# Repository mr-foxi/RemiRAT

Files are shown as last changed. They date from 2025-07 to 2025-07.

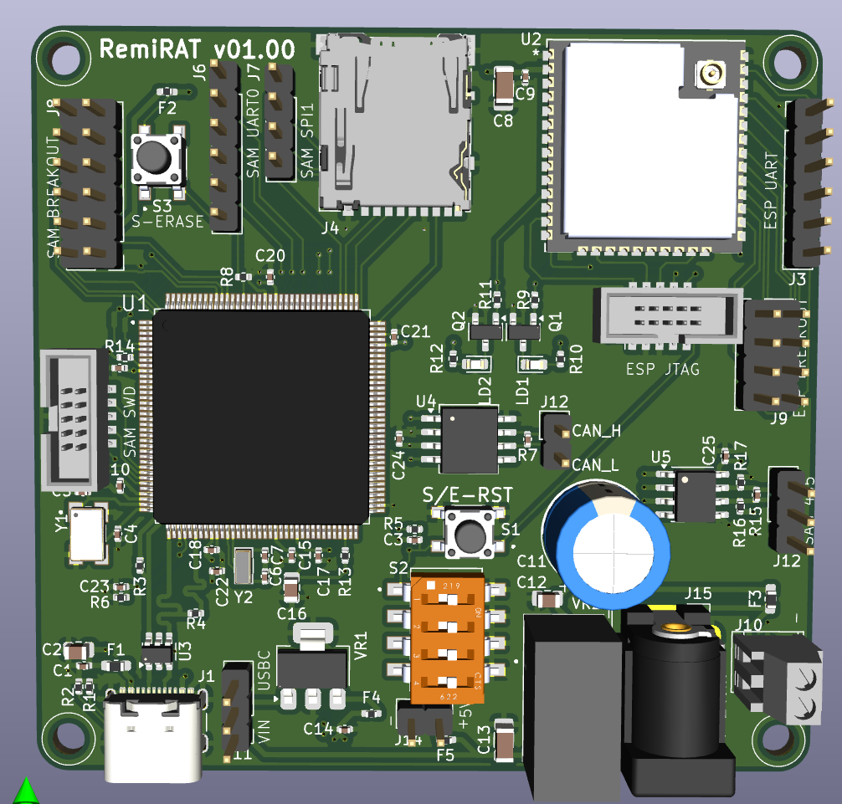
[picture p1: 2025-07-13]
PCB_TOP.png

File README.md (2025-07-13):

# RemiRAT: Versatile Open-Source Wireless Control & Automation Platform
The RemiRAT is a custom PCB that integrates the power of an Arduino Due (SAM3X8EA-AU) with the wireless capabilities of an ESP32-WROOM-32UE-N16 onto a single, compact board. This unified platform condenses complex, multi-board development setups into a streamlined solution, enhancing integration and reliability for advanced control and automation projects.

## Key Features:

Dual Microcontrollers: Combines the SAM3X8EA-AU for high-performance real-time tasks and extensive I/O (including DMA for efficient data handling and RTC support for accurate time-keeping) with the ESP32 for seamless Wi-Fi/Bluetooth connectivity and cloud integration, supporting an external antenna for optimal range.

Robust Industrial Communication: Features dedicated CANBUS (SN65HVD230DR) and MODBUS-RS485 (MAX485CSA+T) transceivers, ensuring reliable data exchange in industrial, automotive, and other demanding environments, complete with proper termination and failsafe biasing for signal integrity.

Diverse Peripherals: Offers comprehensive Digital and Analog I/O, supporting common protocols like UART, SPI, I2C, PWM, and includes a MicroSD card slot for flexible data logging and storage.

Flexible Power Management: Accepts a broad 6.5-32V input via a robust barrel jack or screw terminal, or via USB-C for convenience. It features efficient multi-stage regulation providing stable 5V and 3.3V outputs, backed by integrated fuse protection and USB ESD protection for enhanced durability.

Developer Friendly: Provides multiple options for easy firmware development, including UART, JTAG, and SWD flashing capabilities for both MCUs, along with an ESP32 boot mode DIP switch and clearly labeled breakout headers.

RemiRAT stands as a powerful, robust, and highly integrated solution for tackling complex wireless control and IoT applications with confidence.

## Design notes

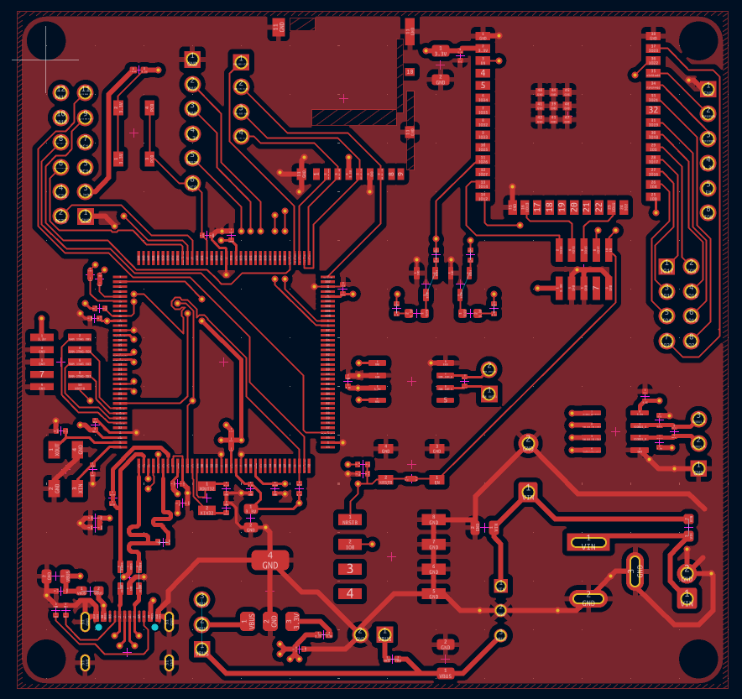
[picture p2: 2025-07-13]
Cu_TOP.png

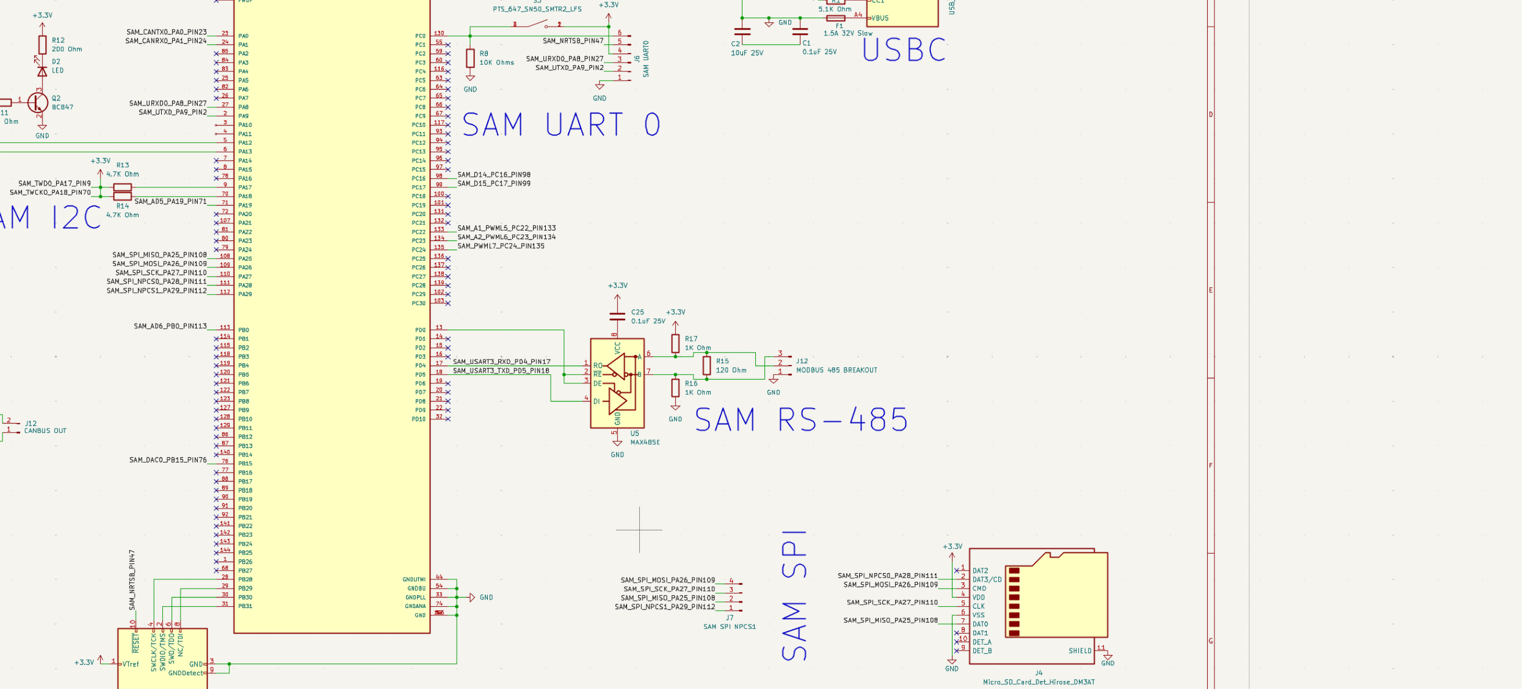
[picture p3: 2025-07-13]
Schem_04.png

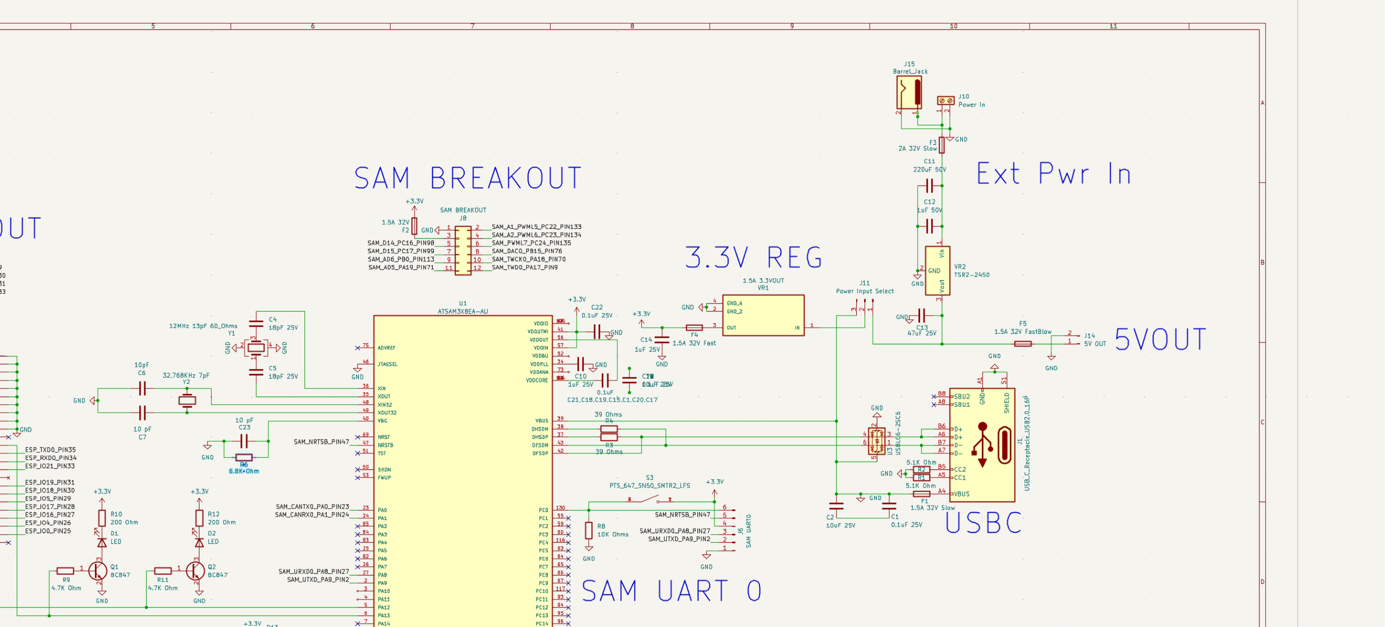
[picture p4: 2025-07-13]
Schem_03.png

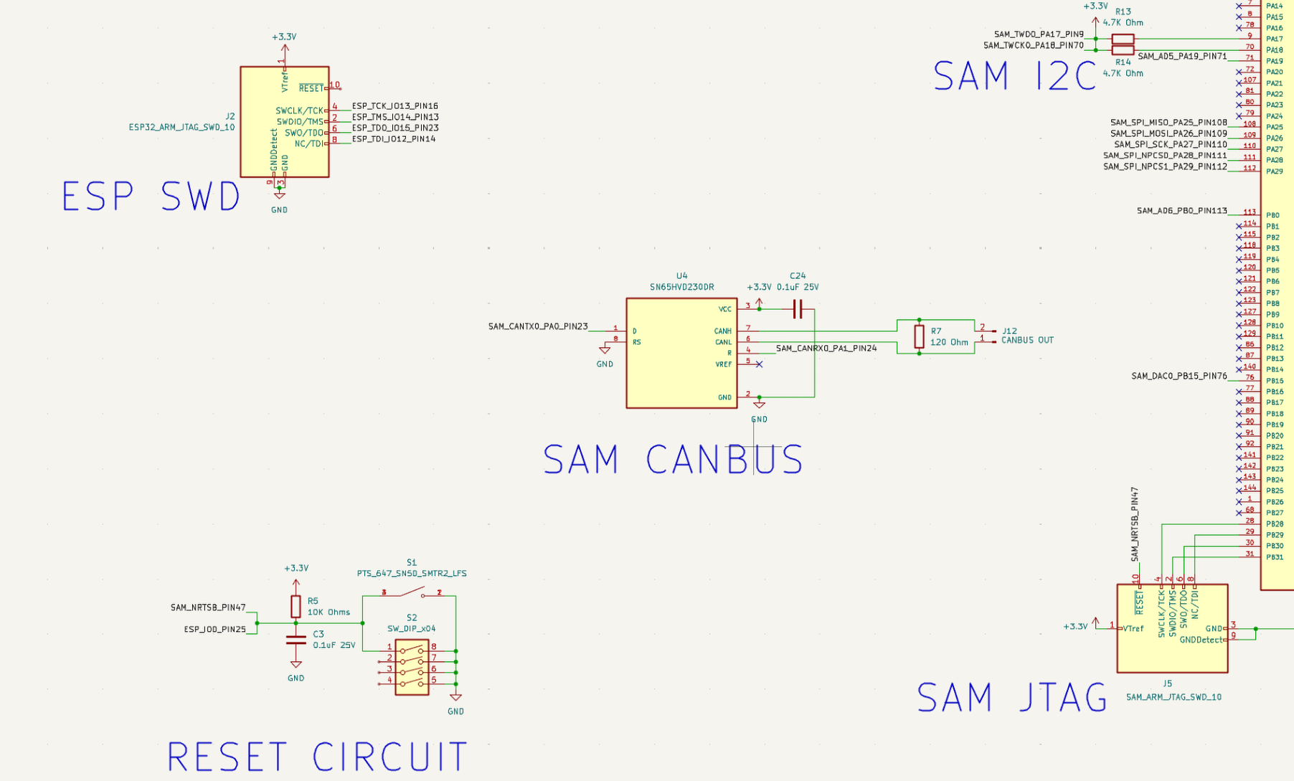
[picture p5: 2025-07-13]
Schem_01.png

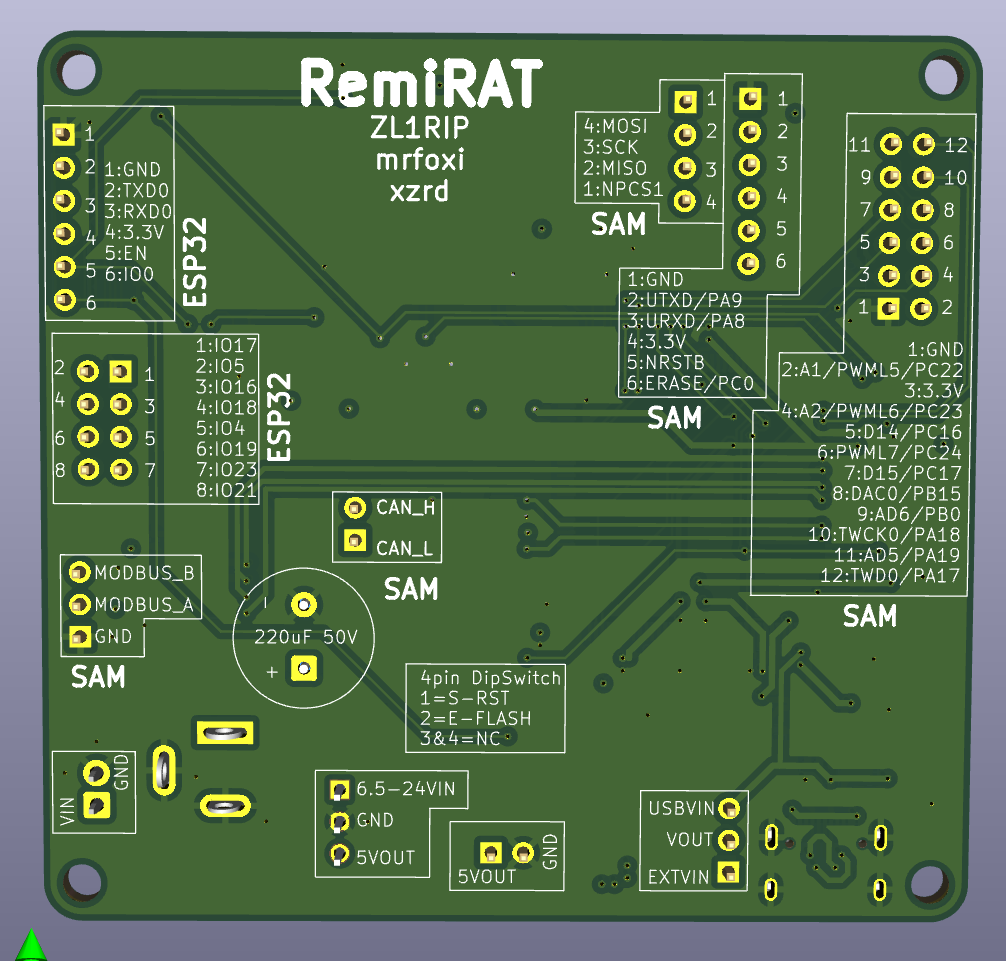
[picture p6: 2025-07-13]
PCB_BOTTOM.png

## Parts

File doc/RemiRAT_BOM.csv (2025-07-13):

Id | Designator | Footprint | Quantity | Designation | Manufacturer | Manufacturer Part Number | Notes
1 | J9 | PinHeader_2x04_P2.54mm_Vertical | 1 | Header 2x04 Pin 2.54mm Vertical | Samtec Inc. | TSW-104-07-F-D | Generic Header
2 | R11,R9,R13 | R_0402_1005Metric | 2 | Resistor 4.7k Ohm 1% 0402 | Yageo | RC0402FR-074K7L | Pull-up/down, specific for SAM or ESP
3 | J3,J6 | PinHeader_1x06_P2.54mm_Vertical | 2 | Header 1x06 Pin 2.54mm Vertical | Würth Elektronik | 61300611121 | e.g., Serial Flashing Headers
4 | C23,C7,C6 | C_0402_1005Metric | 3 | Capacitor 10pF 25V 0402 | KYOCERA AVX | KGM05ACG1E100KH | Crystal Load Capacitors
5 | S3,S1 | SW_PTS_647_SN50_SMTR2_LFS | 2 | Tactile Switch SPST-NO SMD | C&K Components | PTS647SN50SMTR2LFS | Reset/Erase Buttons
6 | Q2,Q1 | SOT-23-3 | 2 | N-Channel MOSFET SOT-23 | Anbon | BC847B | RX/TX LED Transistor
7 | R4,R3 | R_0402_1005Metric | 2 | Resistor 39 Ohm 1% 0402 | Stackpole Electronics Inc | RMCF0402JT39R0 | USB D+/D- Termination
8 | R5,R8 | R_0402_1005Metric | 2 | Resistor 10k Ohm 1% 0402 | Yageo | RC0402FR-0710KL | Pull-up/down for control lines
9 | C8 | C_1206_3216Metric | 1 | Capacitor 22uF 25V X5R 1206 | Samsung Electro-Mechanics | CL31A226KAHNNNE | Bulk Decoupling/Output Cap for ESP32
10 | U1 | QFP50P2200X2200X145-144N | 1 | ATSAM3X8AE-AU MCU | Microchip | ATSAM3X8EA-AU | Main Microcontroller
12 | LD1,LD2 | LED_0603_1608Metric | 2 | LED Green 0603 | Kingbright | APT1608CGCK | RX/TX ESP/SAM LEDs
13 | J4 | microSD_HC_Hirose_DM3AT-SF-PEJM5 | 1 | MicroSD Card Connector | Hirose | DM3AT-SF-PEJM5 | MicroSD Slot
14 | VR1 | SOT-223 | 1 | LDO Regulator 3.3V 1.5A | STMicroelectronics | TL1963A-33DCYR | 3.3V Power Supply
15 | R7,R15 | R_0402_1005Metric | 2 | Resistor 120 Ohm 1% 0402 | Vishay Dale | CRCW0402120RFKEDC | CABUS Noise Resistor
16 | Y1 | XTAL_405C35B12M00000 | 1 | Crystal 12MHz 13pF 4-SMD | CTS-Frequency Controls | 405C35B12M00000 | Main SAM MCU Crystal
17 | R1,R2 | R_0402_1005Metric | 2 | Resistor 5.1k Ohm 1% 0402 | Yageo | RC0402FR-075K1L | Could be USB pull-ups or other
18 | J7 | PinHeader_1x04_P2.54mm_Vertical | 1 | Header 1x04 Pin 2.54mm Vertical | Würth Elektronik | 61300411121 | e.g., Test Points, I2C
19 | R10,R12 | R_0402_1005Metric | 2 | Resistor 200 Ohm 1% 0402 | Delta Electronics/Cyntec | PFR05S-201-FNH | LED Current Limiting
20 | C2,C16 | C_0805_2012Metric | 1 | Capacitor 10uF 25V X5R 0805 | Samsung Electro-Mechanics | CL21A106KAYNNNE | Input/Output Decoupling
21 | J1 | USB_C_Receptacle_GCT_USB4105-xx-A_16P_TopMnt_Horizontal | 1 | USB-C Receptacle Horizontal | GCT | USB4105-GF-A | USB Connector
22 | J2,J5 | PinHeader_2x05_P1.27mm_Vertical_SMD | 2 | Header 2x05 Pin 1.27mm Vert SMD | CNC Tech | 3220-10-0300-00 | e.g., SWD/JTAG Headers
23 | S2 | SW_219-4MST | 1 | DIP Switch 4-Pos SPST | CTS Electrocomponents | 219-4MST | e.g., ESP32 Boot Mode Select
24 | J8 | PinHeader_2x06_P2.54mm_Vertical | 1 | Header 2x06 Pin 2.54mm Vertical | TE Connectivity AMP Connectors | 87227-6 | e.g., Generic Expansion Header
25 | U2 | ESP32-32UE_EXP | 1 | ESP32-WROOM-32UE Module | Espressif Systems | ESP32-WROOM-32UE-N16 | Wi-Fi/BT Module
26 | C4,C5 | C_0402_1005Metric | 2 | Capacitor 18pF 25V C0G 0402 | KYOCERA AVX | KGM05ACG1E180FH | Crystal Load Capacitor
28 | C25,C24,C22,C21,C20,C19,C18,C17,C15,C9,C3,C1 | C_0402_1005Metric | 12 | Capacitor 0.1uF 25V X7R 0402 | Samsung Electro-Mechanics | CL05B104KA5NNNC | Local Decoupling
29 | F2,F5 | Fuse_0402_1005Metric_Pad0.77x0.64mm_HandSolder | 2 | Fuse 1.5A 32V 0402 FastBlow | Littelfuse | 043501.5KRHF | Overcurrent Protection
30 | Y2 | Crystal_SMD_3215-2Pin_3.2x1.5mm | 1 | Crystal 32.768kHz 7pF 3.2x1.5mm | Seiko Instruments | SC32S-7PF20PPM | RTC Crystal for SAM
31 | U3 | SOT-23-6 | 1 | Voltage Supervisor SOT-23-6 | STMicroelectronics | USBLC6-2 | Example, specify part type (e.g. voltage supervisor, op-amp, logic IC)
32 | F3 | Fuse_0603_1608Metric_Pad1.05x0.95mm_HandSolder | 1 | 2A 32V SlowBlow | Bourns Inc. | SF-0603SP200-2 | Wire Input Power Fuse
33 | VR2 | CONV_TSR_2-2450 | 1 | Wire Power Input Voltage Regulator | Traco Power | TSR 2-2450 | 6.5-36VIN 2A 5VOUT
34 | C12 | C_0805_2012Metric | 1 | 1uF 50V | Samsung Electro-Mechanics | CL21B105KBFNNNE
35 | J10 | TerminalBlock_TE_282834-2_1x02_P2.54mm_Horizontal | 1 | 2pin Screw Terminal | TE Connectivity AMP Connectors | 1546215-2
36 | J11,J13 | PinHeader_1x03_P2.54mm_Vertical | 1 | PinHeader_1x03_P2.54mm_Vertical | Würth Elektronik | 61300311121
37 | C13 | C_1206_3216Metric | 1 | 47uF 25V | TDK Corporation | C3216X5R1E476M160AC | Bulk Decoupling/Output Cap for external power in
38 | C10,C14 | C_0402_1005Metric | 2 | Capacitor 1uF 25V X5R 0402 | Samsung Electro-Mechanics | CL05A105KA5NQNC | Local Decoupling
39 | R6 | R_0402_1005Metric | 1 | Resistor 6.8K Ohm 1% 0402 | TE Connectivity Passive Product | CRGCQ0402F6K8 | Voltage Bias Pin Pulldown Resistor
40 | U4 | SOIC-8_5.3x6.2mm_P1.27mm | 1 | 1/1 IC Transceiver Half CANbus 8-SOIC | Texas Instruments | SN65HVD230DR | CANBUS Communication Chip
41 | J12,J14 | PinHeader_1x02_P2.54mm_Vertical | 2 | Header 1x02 Pin 2.54mm Vertical | Würth Elektronik | 61300211121 | CANBUS Breakout
42 | U5 | SOIC-8_5.3x6.2mm_P1.27mm | 1 | 1/1 Transceiver Half RS422, RS485 8-SOIC | Analog Devices Inc./Maxim Integrated | MAX485CSA+T | RS-485 Communication Chip
43 | R16,R17 | R_0402_1005Metric | 2 | Resistor 1K Ohm 1% 0402 | YAGEO | RC0402JR-071KL | Modbus Noise Reduction Resistors
44 | F1 | Fuse_0402_1005Metric_Pad0.77x0.64mm_HandSolder | 1 | Fuse 1.5A 36V 0402 SlowBlow | Bourns Inc. | SF-0603SP150M-2 | USBC Power fuse
45 | J15 | CONN PWR JACK 2.1X5.5MM SOLDER | 1 | Power Barrel Connector Jack 2.10mm ID (0.083"), 5.50mm OD (0.217") Through Hole, Right Angle | Würth Elektronik | 694106301002 | BarrelJack DC Input (2.1mm pin)

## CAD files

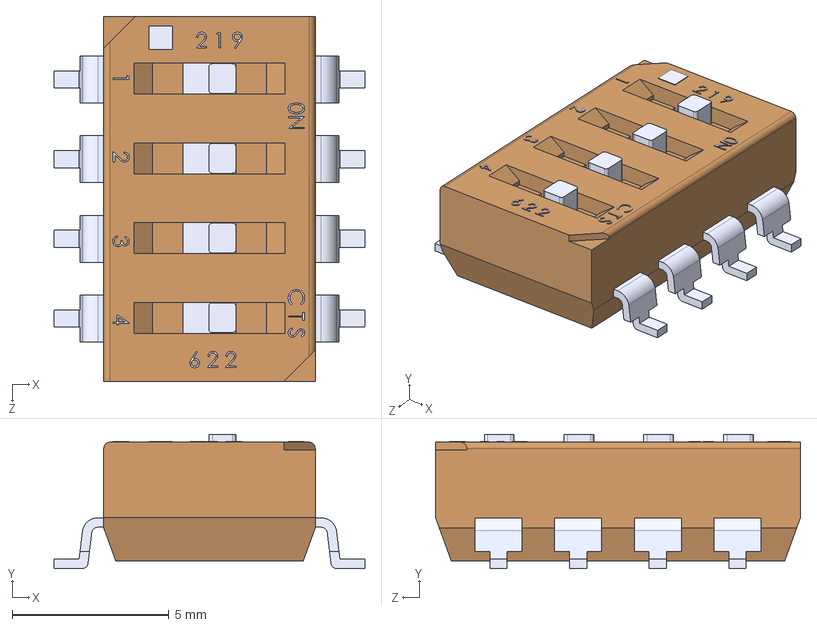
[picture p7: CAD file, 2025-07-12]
coreLib/219_4MST/219-4M.step
9.91 x 4.28 x 11.6 mm

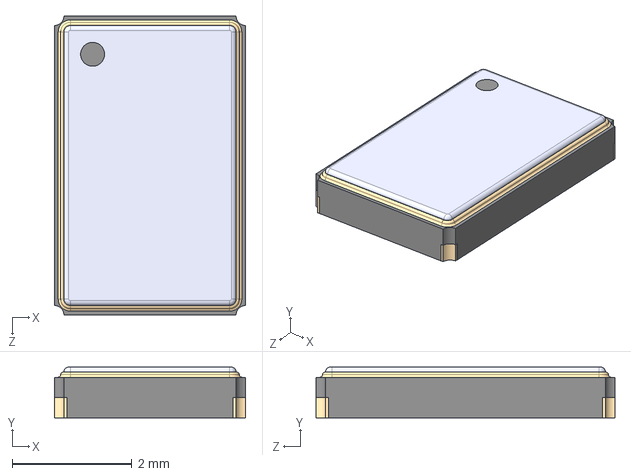
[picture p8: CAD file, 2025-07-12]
coreLib/405C35B12M00000/405C35B12M00000.STEP
3.20 x 0.85 x 5.00 mm

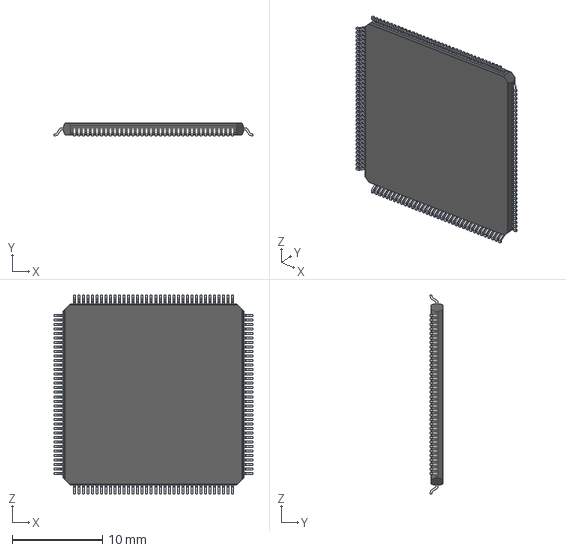
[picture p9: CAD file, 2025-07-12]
coreLib/ATSAM3X8EA_AU/atsam3x8ea-au.stp
22.0 x 1.40 x 22.0 mm

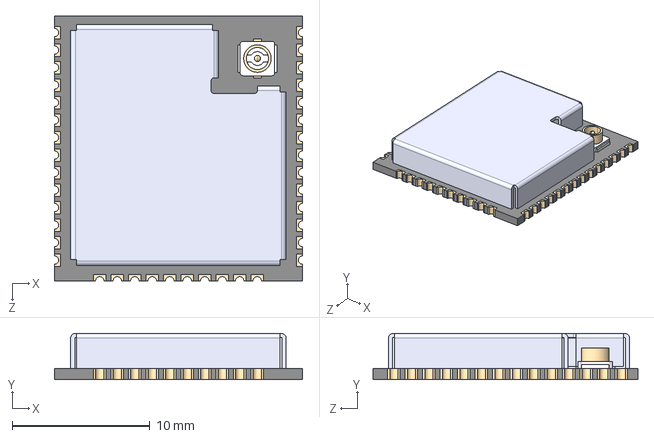
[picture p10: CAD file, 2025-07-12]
coreLib/ESP32-WROOM-32UE-N16/ESP32-WROOM-32UE-N16.STEP
18.0 x 3.35 x 19.2 mm

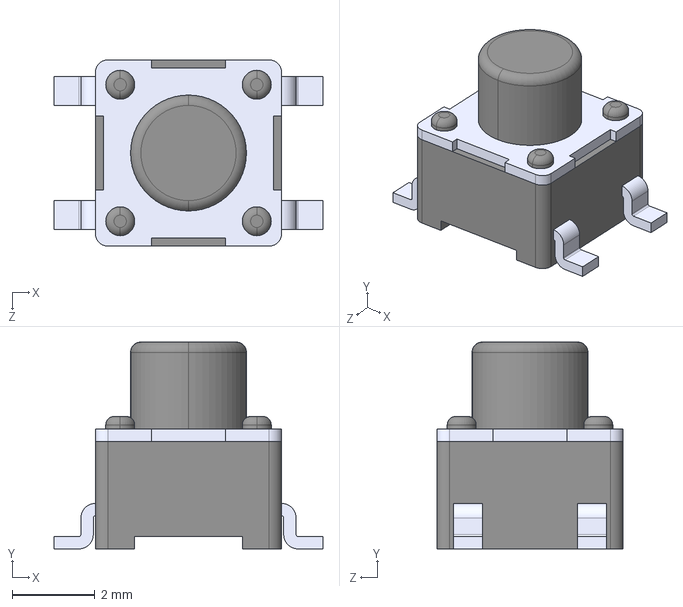
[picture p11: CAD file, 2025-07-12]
coreLib/PTS_647_SN50_SMTR2_LFS/PTS_647_SN50_SMTR2_LFS.step
6.50 x 5.00 x 4.50 mm

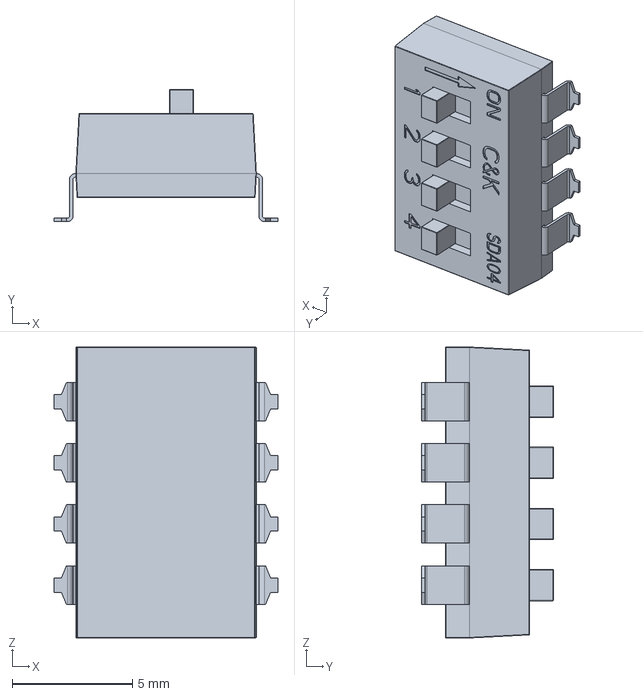
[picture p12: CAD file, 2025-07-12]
coreLib/SDA04H1SBD/SDA04H1SBD.stp
9.30 x 5.50 x 12.1 mm

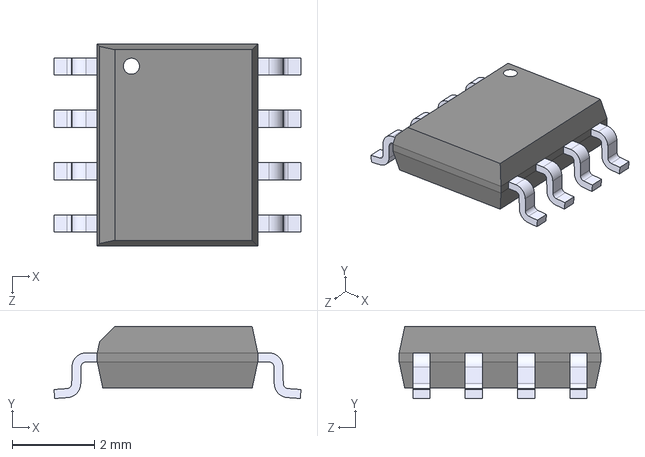
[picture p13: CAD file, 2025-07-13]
coreLib/SN65HVD230DR/SN65HVD230DR.step
6.00 x 1.75 x 4.90 mm

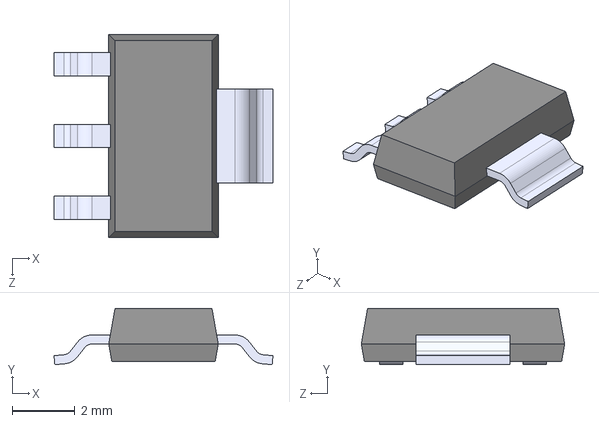
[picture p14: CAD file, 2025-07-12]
coreLib/TL1963A_33DCYR/TL1963A-33DCYR.step
7.00 x 1.80 x 6.50 mm

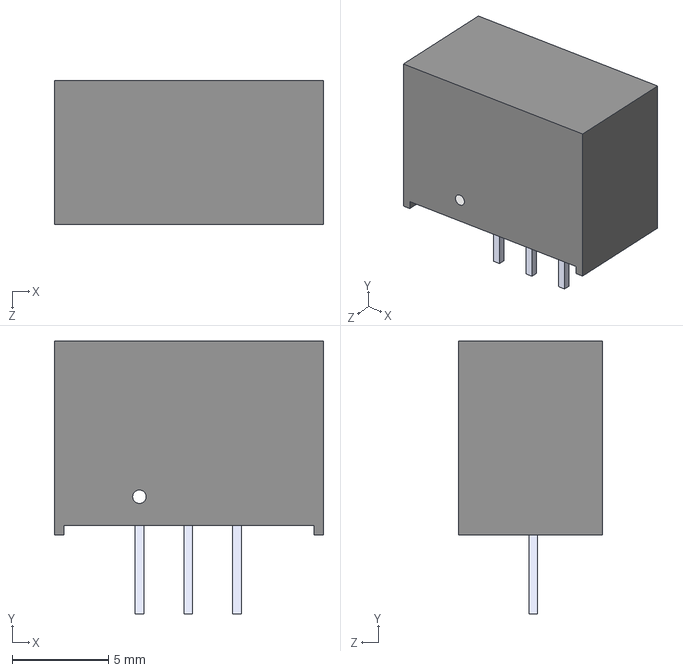
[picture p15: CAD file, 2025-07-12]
coreLib/TSR_2_2450/TSR_2-2450.step
14.0 x 14.2 x 7.50 mm

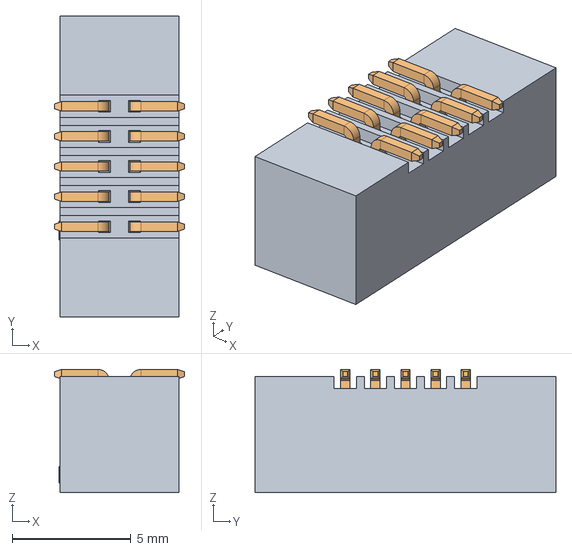
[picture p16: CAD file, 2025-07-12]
coreLib/3220-10-0300-00 3D.stp
5.50 x 12.7 x 5.20 mm
802-2195SM-XXG x 10

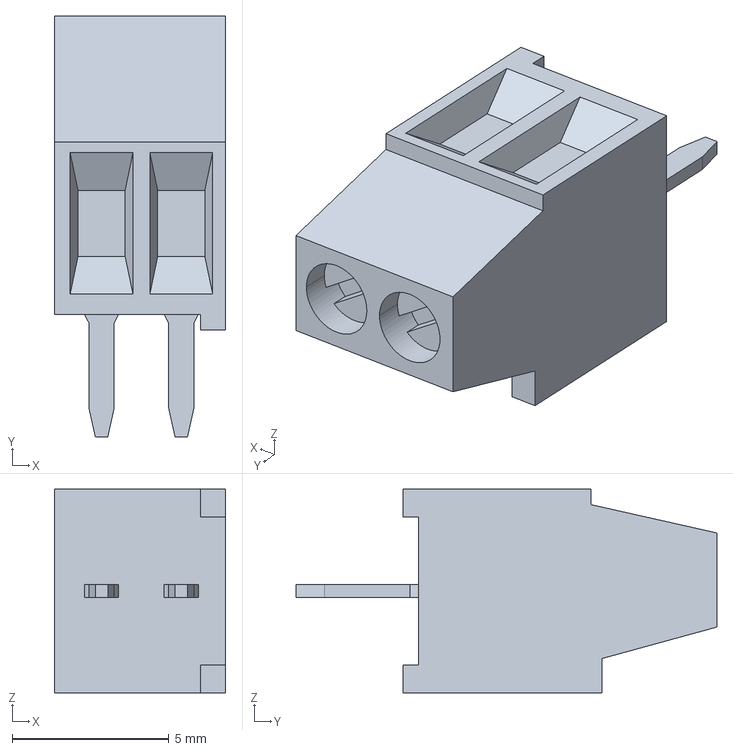
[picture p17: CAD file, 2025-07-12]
coreLib/1546215-2.STEP
5.45 x 13.4 x 6.50 mm

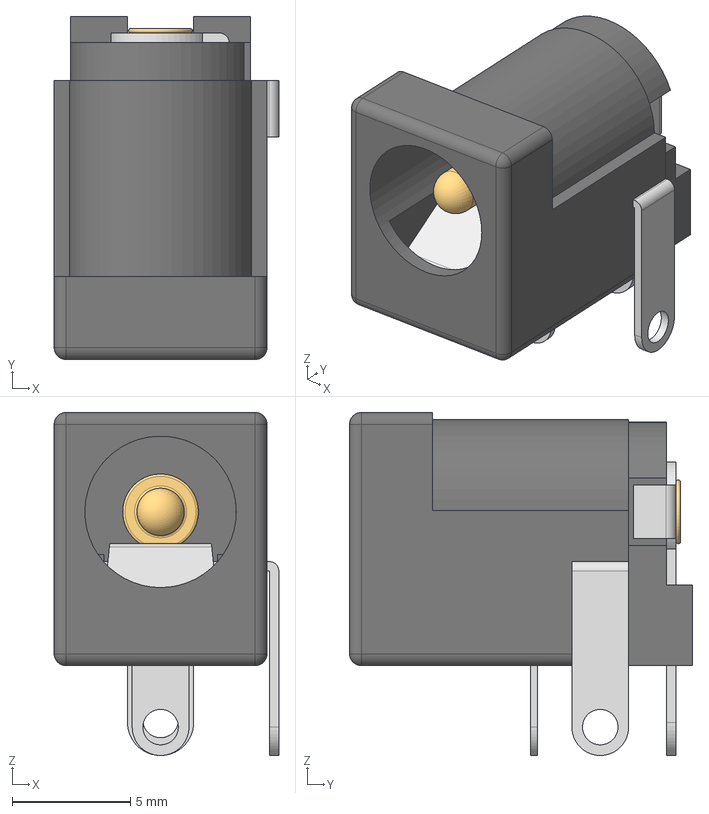
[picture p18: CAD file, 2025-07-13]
coreLib/694106301002/694106301002.step
9.50 x 14.5 x 14.5 mm
6941xx301002
694106301002_PinContact
6941xx301002_Back
6941xx301002_PinContact2
6941xx301002_PinLame
6941xx301002_PinBis

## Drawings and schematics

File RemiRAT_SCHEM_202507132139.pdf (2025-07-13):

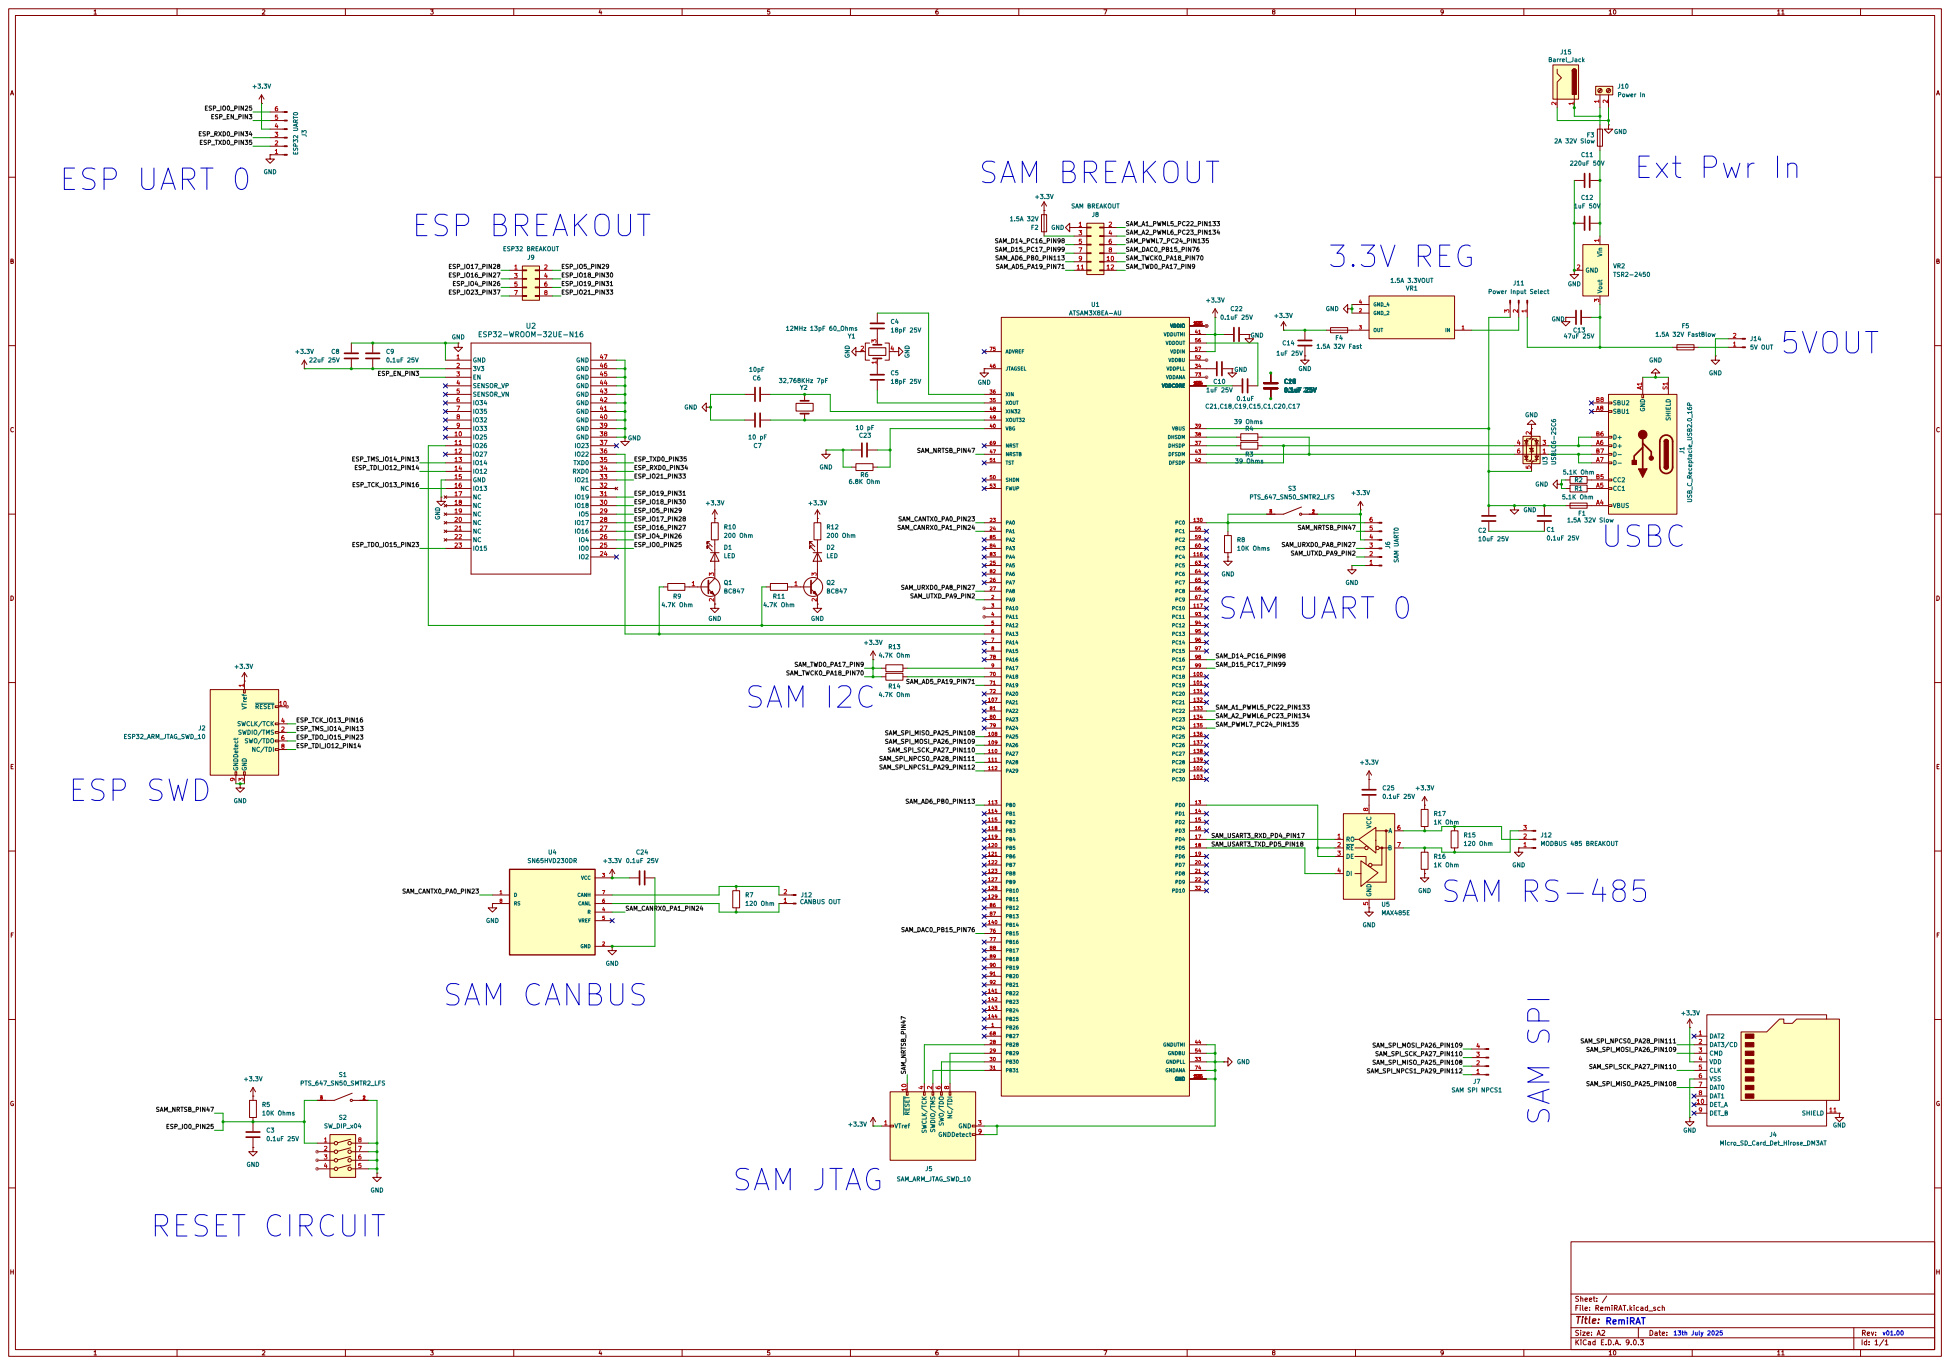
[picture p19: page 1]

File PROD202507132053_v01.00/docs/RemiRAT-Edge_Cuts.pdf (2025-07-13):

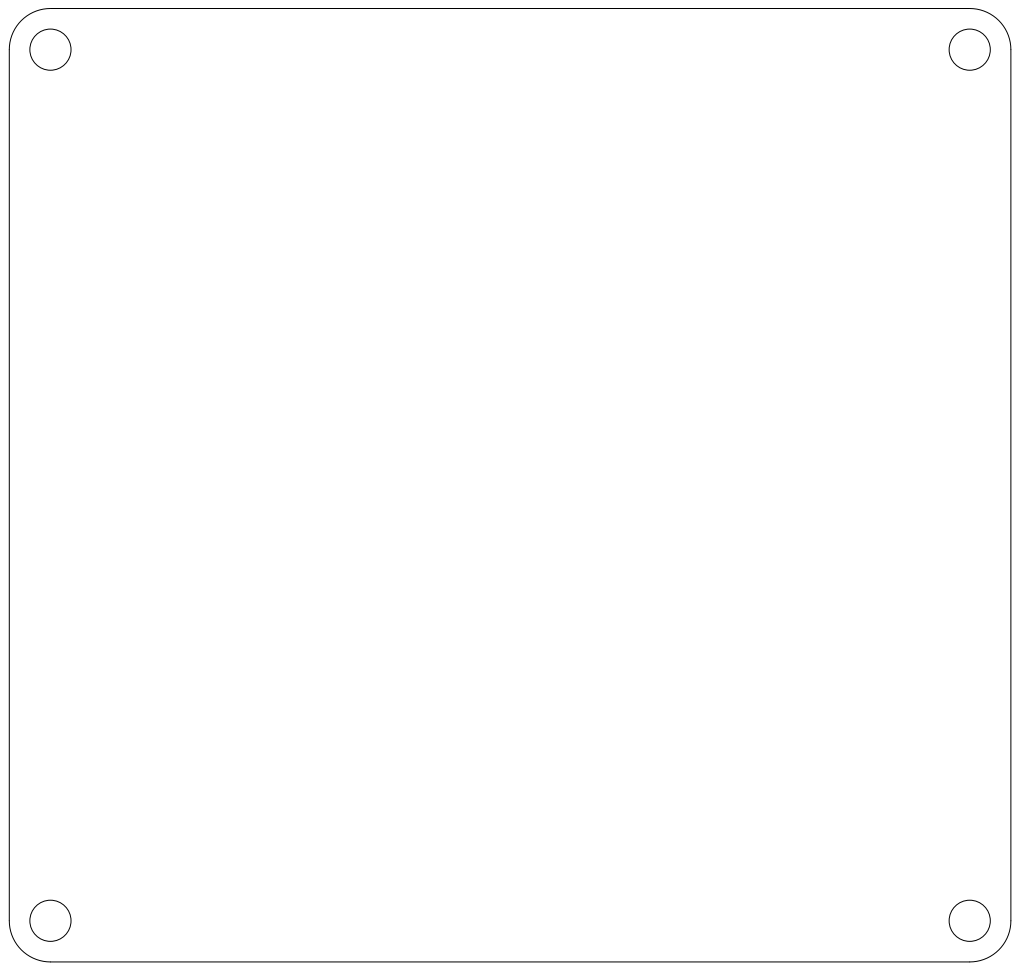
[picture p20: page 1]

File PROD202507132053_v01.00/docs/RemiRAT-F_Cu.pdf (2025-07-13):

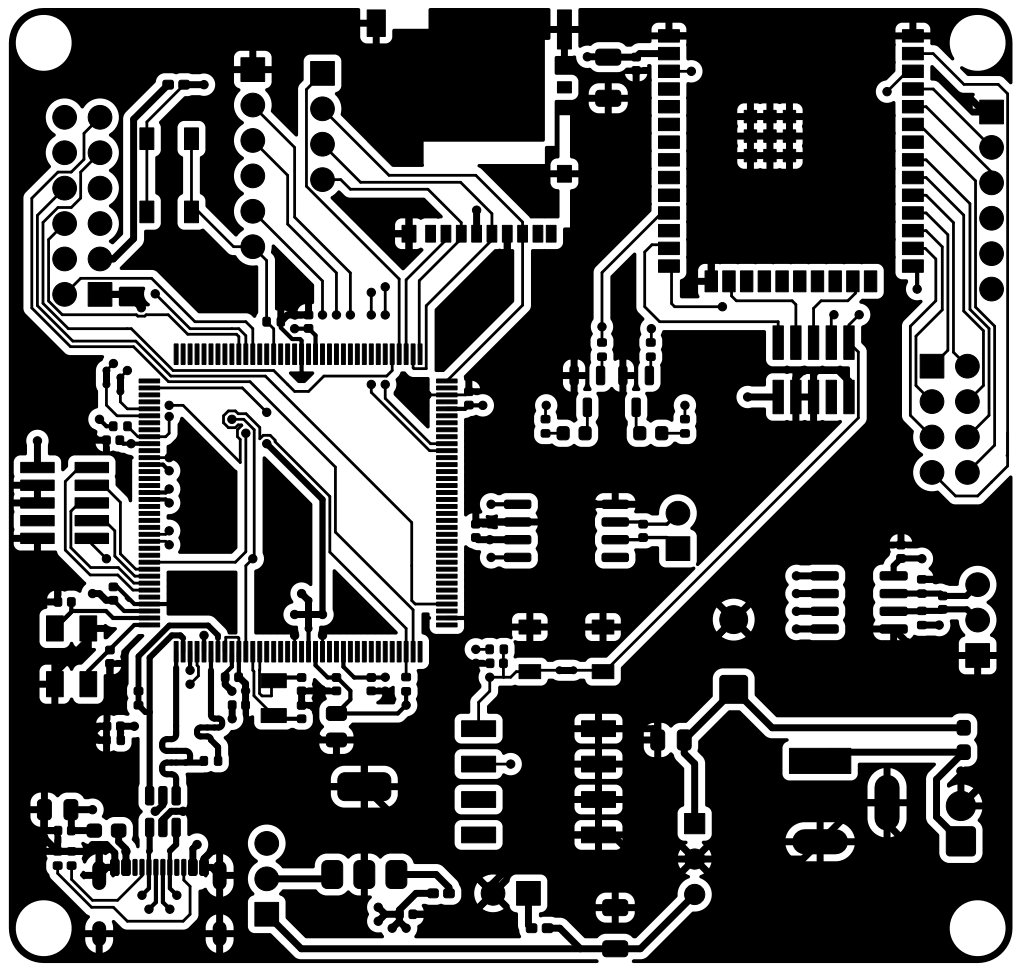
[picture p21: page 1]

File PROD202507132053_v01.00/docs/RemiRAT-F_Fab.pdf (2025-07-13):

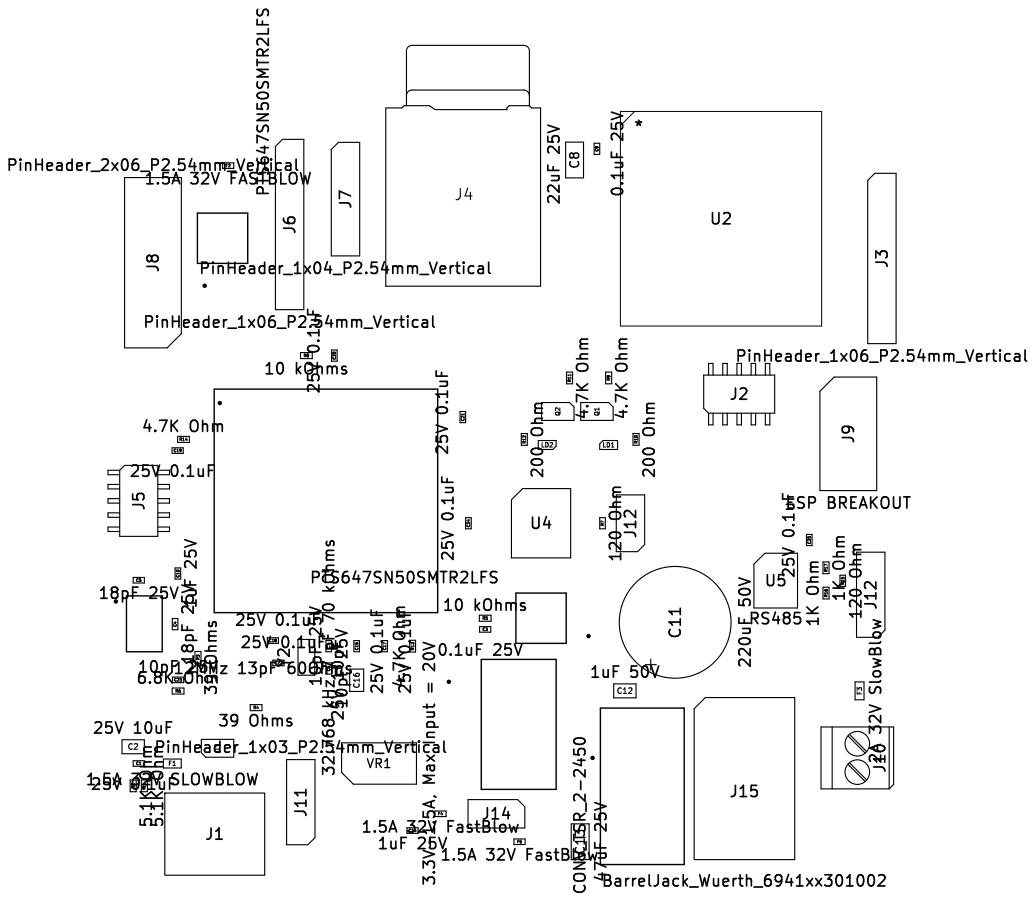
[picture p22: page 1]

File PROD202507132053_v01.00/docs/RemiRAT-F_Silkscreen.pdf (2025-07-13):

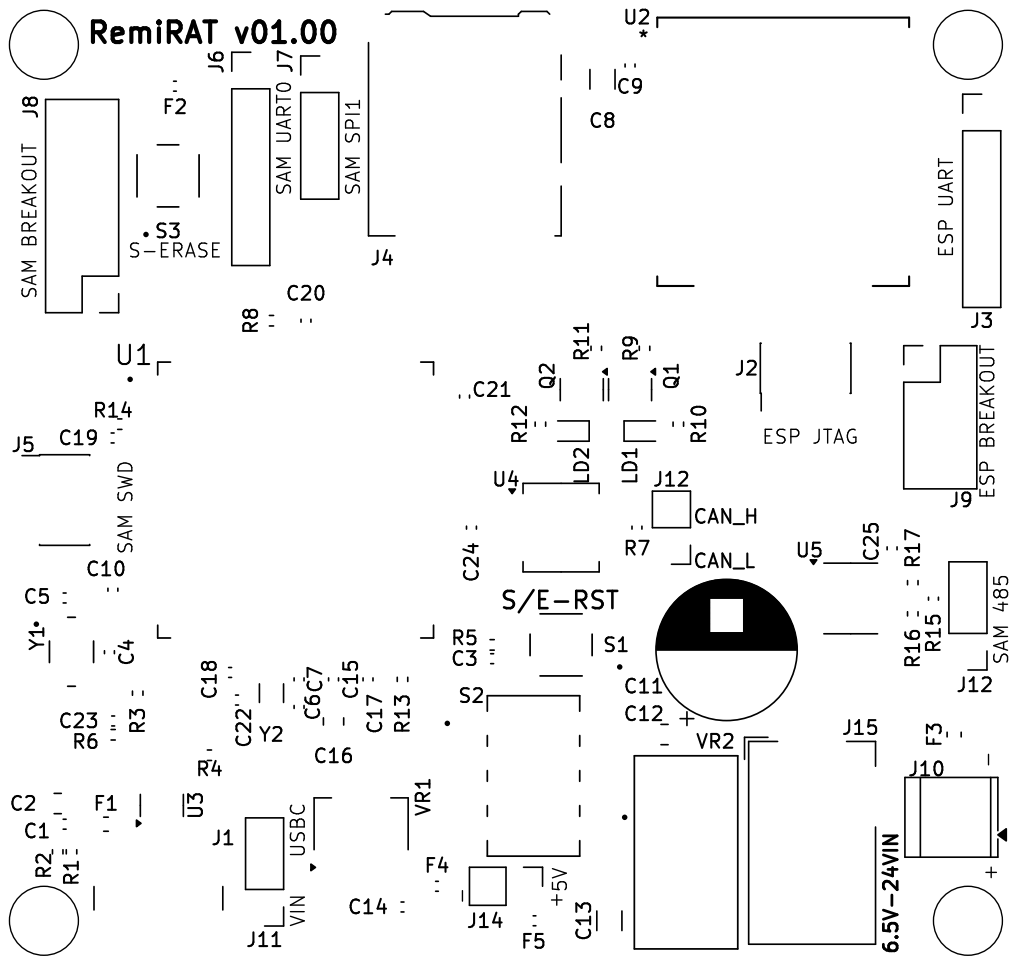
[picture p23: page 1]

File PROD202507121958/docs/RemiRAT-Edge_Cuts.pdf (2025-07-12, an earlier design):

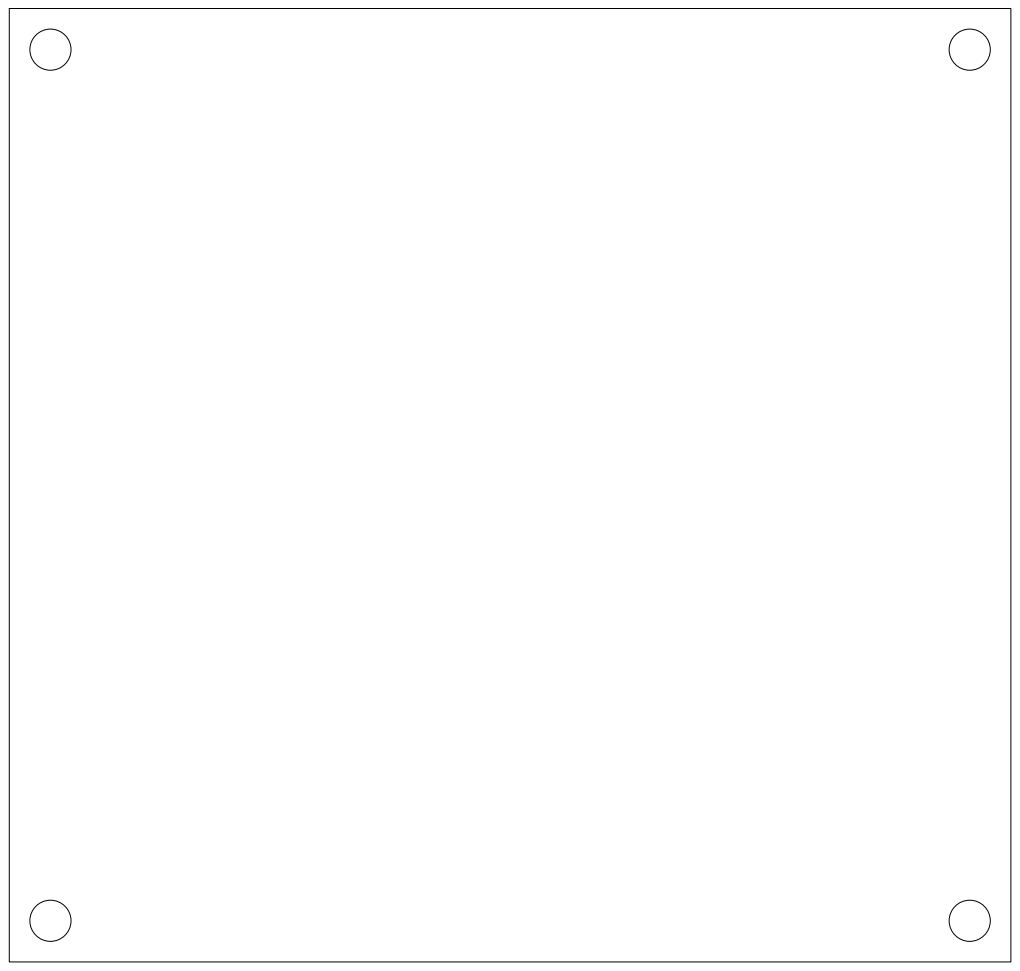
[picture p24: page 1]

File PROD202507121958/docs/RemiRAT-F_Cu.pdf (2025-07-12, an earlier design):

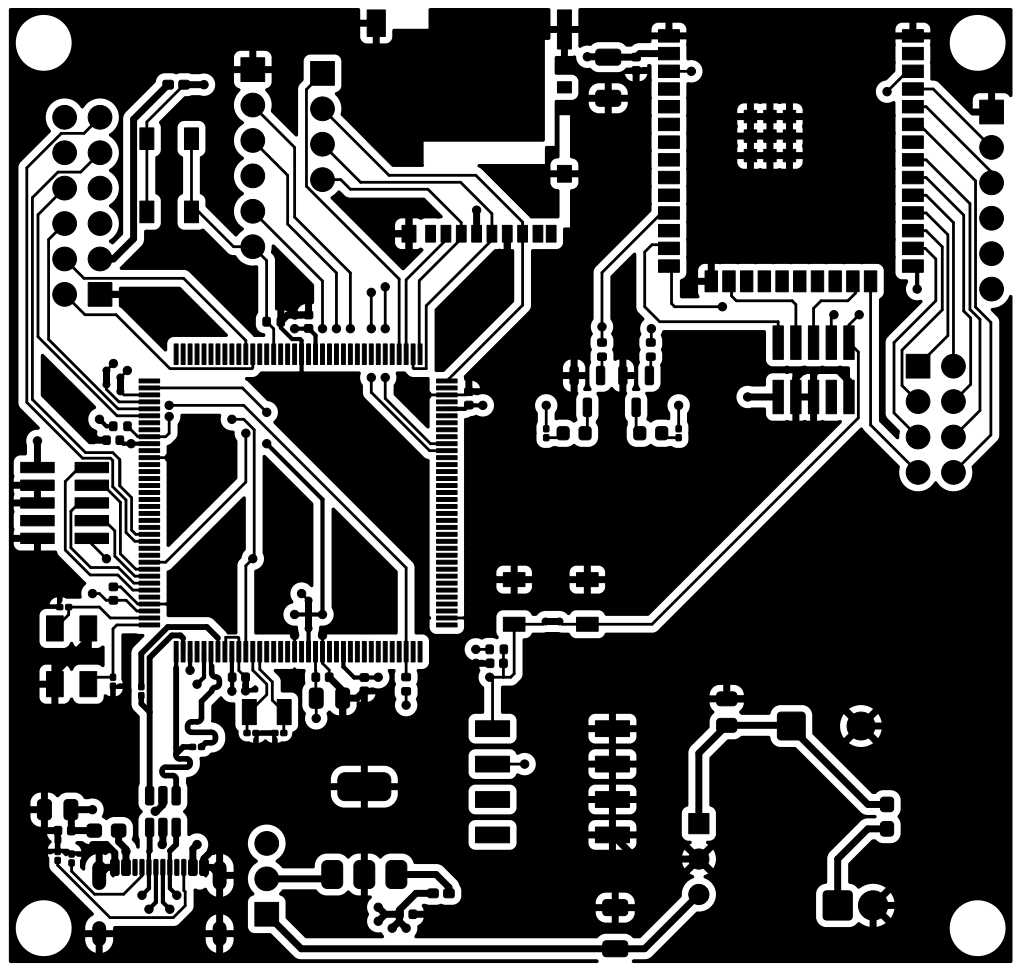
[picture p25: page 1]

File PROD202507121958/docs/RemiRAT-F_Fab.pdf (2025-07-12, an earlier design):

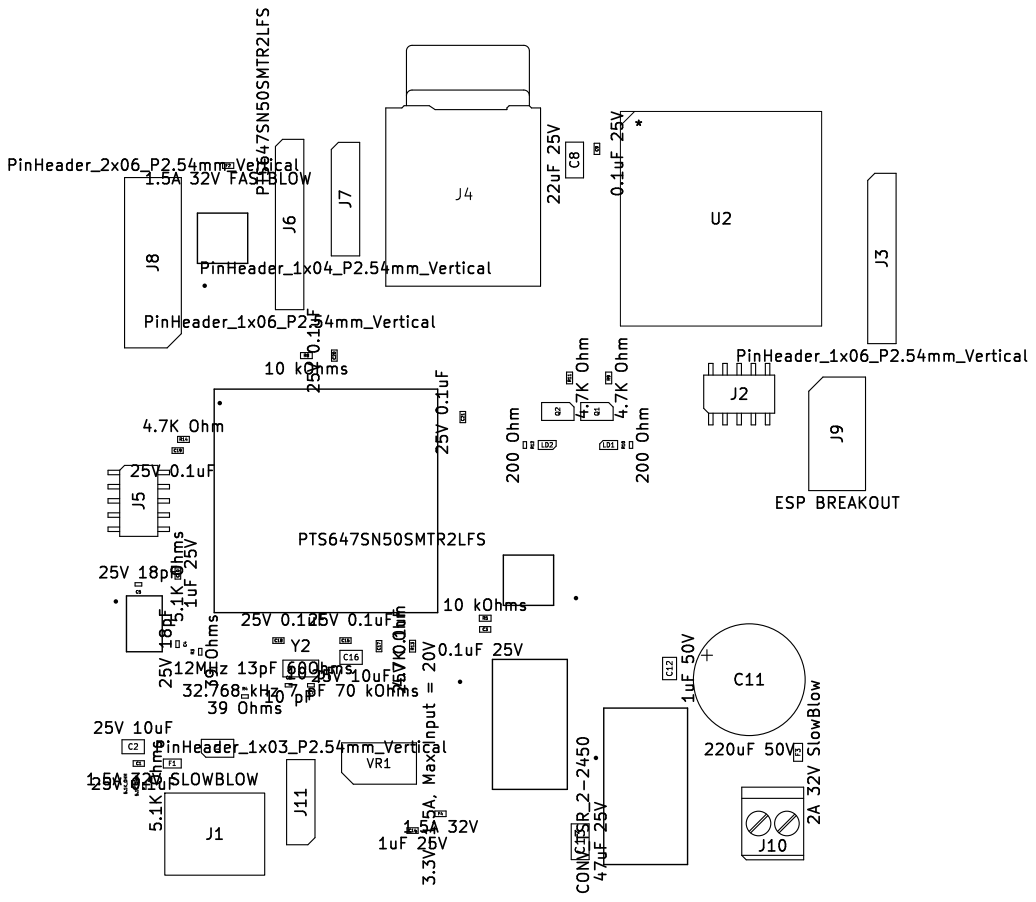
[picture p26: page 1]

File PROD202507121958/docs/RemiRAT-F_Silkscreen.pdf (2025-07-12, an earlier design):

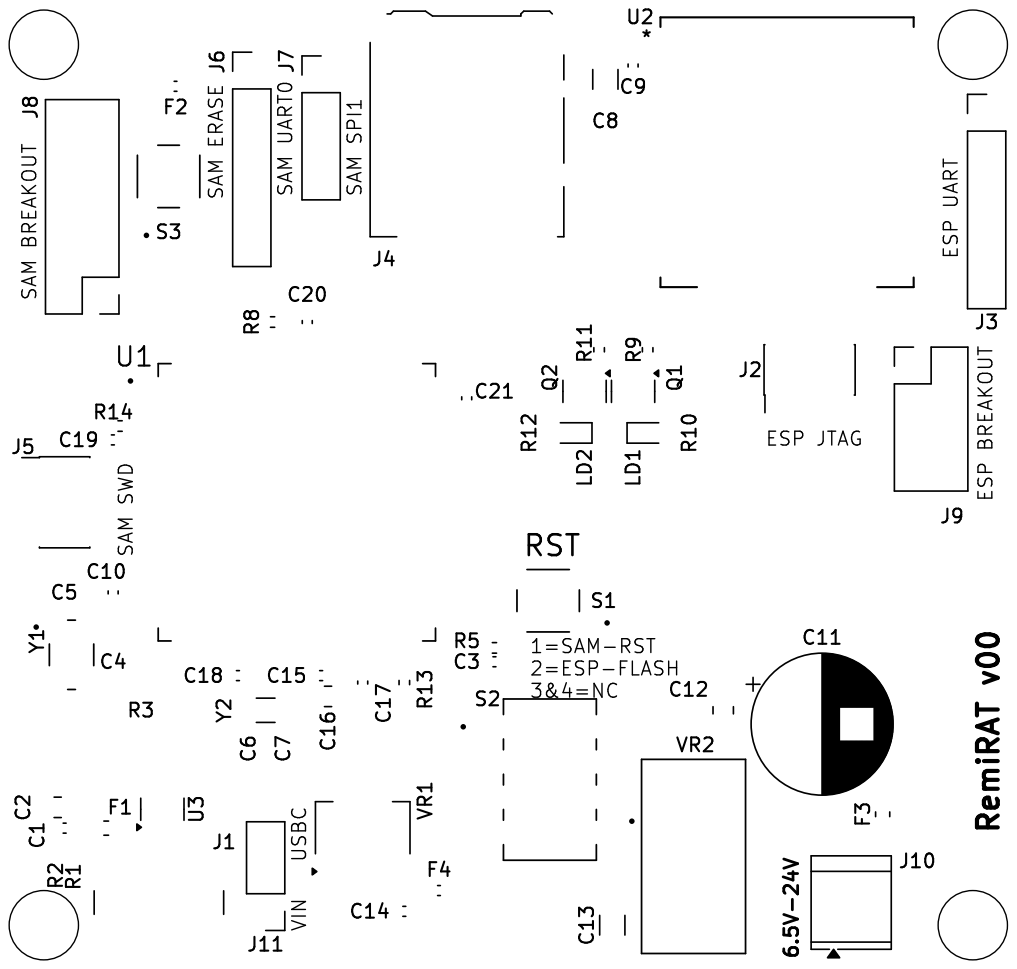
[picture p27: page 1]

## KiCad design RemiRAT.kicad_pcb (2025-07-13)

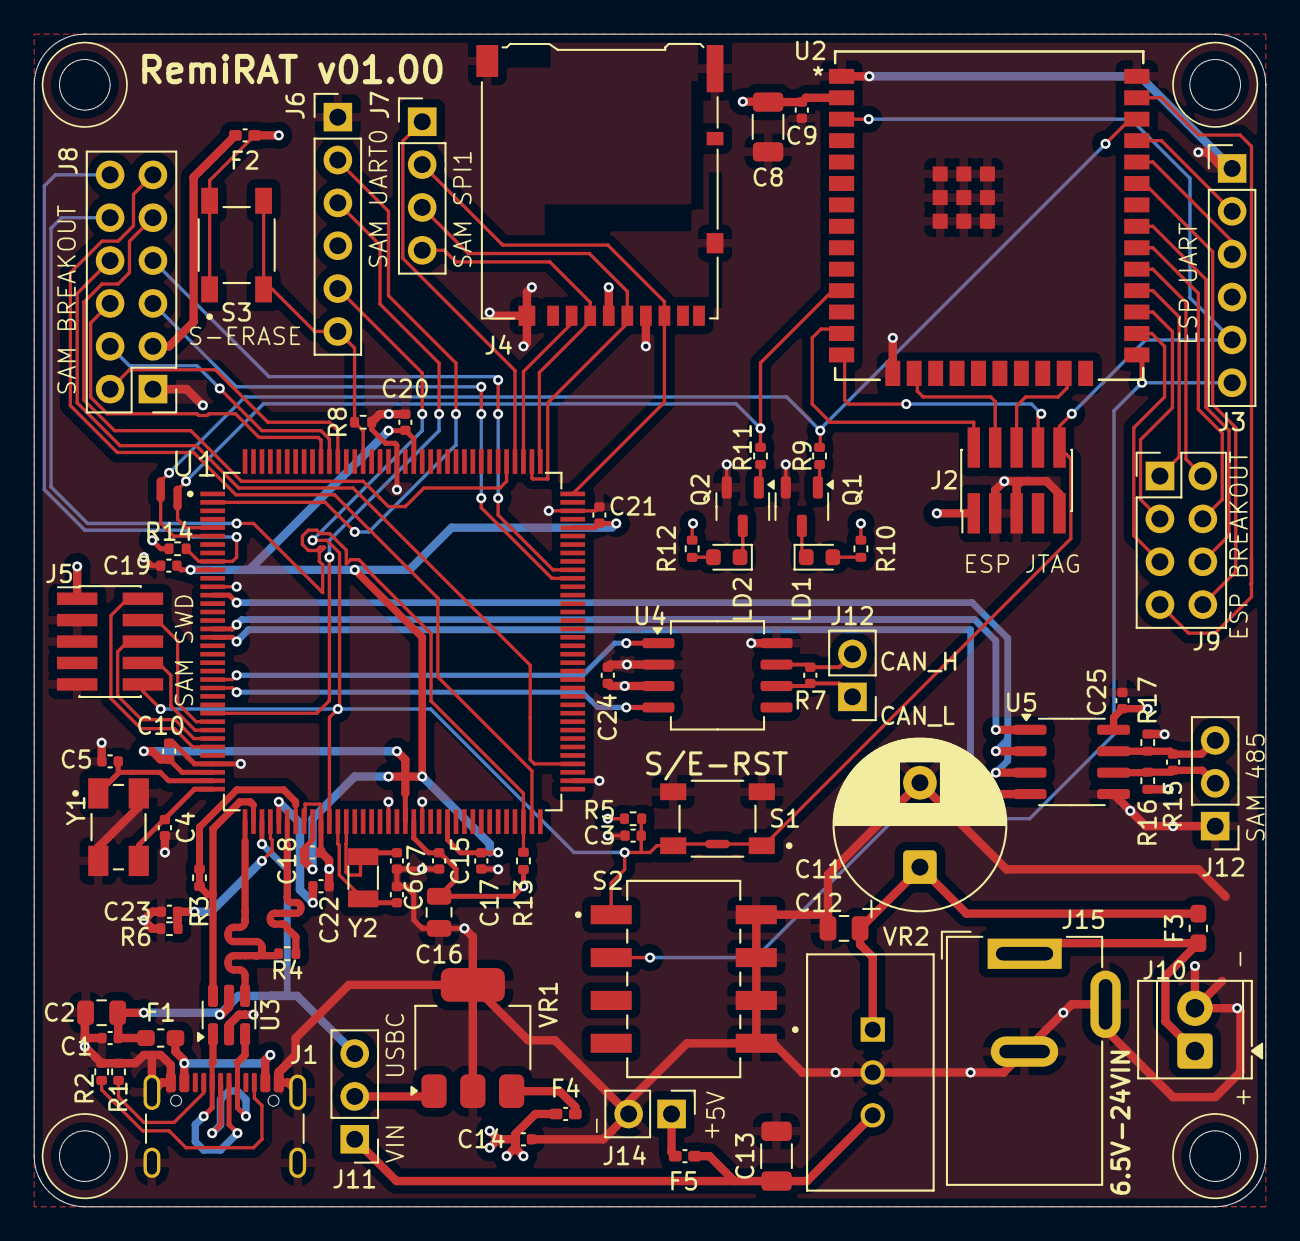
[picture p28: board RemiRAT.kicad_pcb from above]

Board: 4 copper layers, 73.0 x 69.5 mm, 78 parts (0 on the bottom side), 67 nets.

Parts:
C1, C15, C17, C18, C19, C20, C21, C22, C24, C25: 25V 0.1uF; C_0402_1005Metric
C2, C16: 25V 10uF; C_0805_2012Metric
C3, C9: 0.1uF 25V; C_0402_1005Metric
C4, C5: 18pF 25V; C_0402_1005Metric
C6, C7, C23: 10pF 25V; C_0402_1005Metric
C8: 22uF 25V; C_1206_3216Metric
C10, C14: 1uF 25V; C_0402_1005Metric
C11: 220uF 50V; CP_Radial_D10.0mm_P5.00mm
C12: 1uF 50V; C_0805_2012Metric
C13: 47uF 25V; C_1206_3216Metric
F1: 1.5A 32V SLOWBLOW; Fuse_0603_1608Metric_Pad1.05x0.95mm_HandSolder
F2: 1.5A 32V FASTBLOW; Fuse_0402_1005Metric_Pad0.77x0.64mm_HandSolder
F3: 2A 32V SlowBlow; Fuse_0603_1608Metric_Pad1.05x0.95mm_HandSolder
F4, F5: 1.5A 32V FastBlow; Fuse_0402_1005Metric_Pad0.77x0.64mm_HandSolder
J1: USB_C_Receptacle_GCT_USB4105-xx-A_16P_TopMnt_Horizontal
J2, J5: PinHeader_2x05_P1.27mm_Vertical_SMD
J3, J6: PinHeader_1x06_P2.54mm_Vertical
J4: microSD_HC_Hirose_DM3AT-SF-PEJM5
J7: PinHeader_1x04_P2.54mm_Vertical
J8: PinHeader_2x06_P2.54mm_Vertical
J9: ESP BREAKOUT; PinHeader_2x04_P2.54mm_Vertical
J10: TerminalBlock_TE_282834-2_1x02_P2.54mm_Horizontal
J11: PinHeader_1x03_P2.54mm_Vertical
J12, J14: PinHeader_1x02_P2.54mm_Vertical
J12#2: PinHeader_1x03_P2.54mm_Vertical
J15: BarrelJack_Wuerth_6941xx301002
LD1, LD2: LED_0603_1608Metric
Q1, Q2: SOT-23-3
R1, R2: 5.1K Ohm; R_0402_1005Metric
R3, R4: 39 Ohms; R_0402_1005Metric
R5, R8: 10 kOhms; R_0402_1005Metric
R6: 6.8K Ohm; R_0402_1005Metric
R7, R15: 120 Ohm; C_0402_1005Metric
R9, R11, R13, R14: 4.7K Ohm; R_0402_1005Metric
R10, R12: 200 Ohm; R_0402_1005Metric
R16, R17: 1K Ohm; R_0402_1005Metric
S1, S3: PTS647SN50SMTR2LFS; SW_PTS_647_SN50_SMTR2_LFS
S2: SW_219-4MST
U1: QFP50P2200X2200X145-144N
U2: ESP32-32UE_EXP
U3: SOT-23-6
U4: SOIC-8_5.3x6.2mm_P1.27mm
U5: RS485; SOIC-8_3.9x4.9mm_P1.27mm
VR1: 3.3V-1.5A, Max Input = 20V; SOT-223
VR2: CONV_TSR_2-2450
Y1: 12MHz 13pF 60Ohms; XTAL_405C35B12M00000
Y2: 32.768 kHz 7 pF 70 kOhms; Crystal_SMD_3215-2Pin_3.2x1.5mm

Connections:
3.3V: C8.1, C9.1, C14.1, C15.1, C16.1, C24.1, C25.1, F2.2, F4.1, F4.2, J2.1, J3.4, J4.4, J5.1, J6.4, LD1.2, LD2.2, R5.2, R10.1, R10.2, R12.1, R12.2, R13.2, R14.2, R16.2, S3.1, S3.2, U1.57, U2.2, U4.3, U5.8, VR1.3
3.3VOUT: F2.1, J8.3
A1/PWML5/PC22: J8.2, U1.133
A2/PWML6/PC23: J8.4, U1.134
CANRX0/PA1: U1.24, U4.4
CANTX0/PA0: U1.23, U4.1
CAN_OUT_H: J12.2, R7.2, U4.7
CAN_OUT_L: J12.1, R7.1, U4.6
CC1: J1.A5, R1.1
CC2: J1.B5, R2.1
D14/PC16: J8.5, U1.98
D15/PC17: J8.7, U1.99
EN: J2.10, J3.5, S1.1, U2.3
ERASE/PC0: J6.6, R8.1, S3.3, S3.4, U1.130
ESP32RXD0: J3.3, U2.34
ESP32TXD0: J3.2, U2.35
GND: C1.2, C2.2, C3.2, C4.1, C5.1, C6.2, C7.2, C8.2, C9.2, C10.2, C11.2, C12.2, C13.2, C14.2, C15.2, C16.2, C17.2, C18.2, C19.2, C20.2, C21.2, C22.2, C23.2, C24.2, C25.2, J1.A1, J1.A12, J1.B1, J1.B12, J1.S1, J2.3, J2.5, J2.9, J3.1, J4.6, J4.11, J5.3, J5.5, J5.9, J6.1, J8.1, J10.2, J12#2.1, J14.2, J15.2, J15.3, Q1.2, Q2.2, R1.2, R2.2, R6.2, R8.2, R17.2, S1.3, S1.4, S2.5, S2.6, S2.7, S2.8, U1.12, U1.33, U1.44, U1.46, U1.54, U1.58, U1.74, U1.106, U1.126, U2.1, U2.15, U2.38, U2.39, U2.40, U2.41, U2.42, U2.43, U2.44, U2.45, U2.46, U2.47, U3.2, U4.2, U4.8, U5.5, VR1.2, VR1.4, VR2.2, Y1.2, Y1.4
IO0: J3.6, S2.2, U2.25
IO4: J9.5, U2.26
IO5: J9.2, U2.29
IO16: J9.3, U2.27
IO17: J9.1, U2.28
IO18: J9.4, U2.30
IO19: J9.6, U2.31
IO21: J9.8, U2.33
IO22: LD1.1, Q1.1, Q1.3, R9.1, R9.2, U2.36
IO23: J9.7, U2.37
IO26: LD2.1, Q2.1, Q2.3, R11.1, R11.2, U2.11
MODBUS_A: J12#2.2, R15.1, R16.1, U5.6
MODBUS_B: J12#2.3, R15.2, R17.1, U5.7
NRSTB: C3.1, J5.10, J6.5, R5.1, S1.2, S2.1, U1.47
SAM-JTAG-TCK: J5.4, U1.28
SAM-JTAG-TDI: J5.8, U1.29
SAM-JTAG-TDO: J5.6, U1.30
SAM-JTAG-TMS: J5.2, U1.31
SAM-SPI-MISO: J4.7, J7.2, U1.108
SAM-SPI-MOSI: J4.3, J7.4, U1.109
SAM-SPI-NPCS0: J4.2, U1.111
SAM-SPI-NPCS1: J7.1, U1.112
SAM-SPI-SCK: J4.5, J7.3, U1.110
SAM_A10_PD0_PIN13: U1.13, U5.2, U5.3
SAM_AD5_PA19_PIN71: J8.11, U1.71
SAM_AD6_PB0_PIN113: J8.9, U1.113
SAM_DAC0_PB15_PIN76: J8.8, U1.76
SAM_PWML7_PC24_PIN135: J8.6, U1.135
SAM_USART3_RXD_PD4_PIN17: U1.17, U5.1
SAM_USART3_TXD_PD5_PIN18: U1.18, U5.4
TCK/IO13: J2.4, U2.16
TDI/IO12: J2.8, U2.14
TDO/IO15: J2.6, U2.23
TMS/IO14: J2.2, U2.13
TWCK0/PA18: J8.10, R13.1, U1.70
TWD0/PA17: J8.12, R14.1, U1.9
URXD/PA8: J6.3, U1.27
USBDM: J1.A7, J1.B7, R3.1, R3.2, U1.38, U1.43, U3.1, U3.6
USBDP: J1.A6, J1.B6, R4.1, R4.2, U1.37, U1.42, U3.3, U3.4
UTXD/PA9: J6.2, U1.2
VBG: C23.1, R6.1, U1.40
VBUS: C1.1, C2.1, C13.1, F1.1, F1.2, F5.1, F5.2, J1.A4, J1.A9, J1.B4, J1.B9, J11.1, J11.2, J11.3, J14.1, U1.39, U3.5, VR1.1, VR2.3
VDDCORE: C17.1, C18.1, C19.1, C20.1, C21.1, U1.10, U1.45, U1.61, U1.104, U1.124
VDDPLL: C10.1, U1.34
VDDUTMI: C22.1, U1.41
VIN: C11.1, C12.1, F3.1, F3.2, J10.1, J15.1, VR2.1
XIN: C4.2, U1.36, Y1.3
XIN32: C6.1, U1.48, Y2.2
XOUT: C5.2, U1.35, Y1.1
XOUT32: C7.1, U1.49, Y2.1
